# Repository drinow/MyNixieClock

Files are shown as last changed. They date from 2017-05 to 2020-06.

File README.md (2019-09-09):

# 辉光钟--By drinow
## 条目解释
- MyNixie/Version2.0为工程文件，其余为一些资料或者测试数据

## 实物图
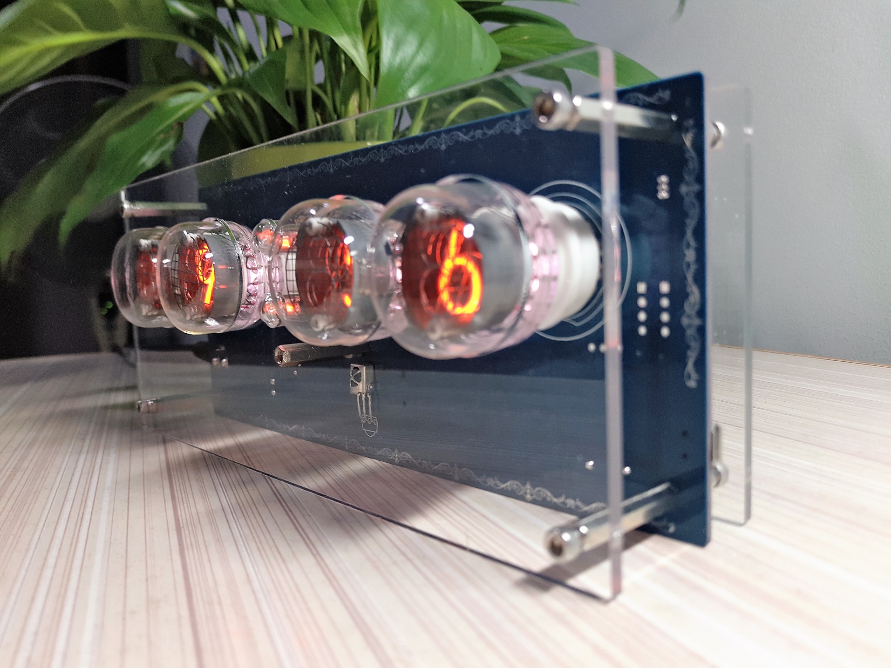
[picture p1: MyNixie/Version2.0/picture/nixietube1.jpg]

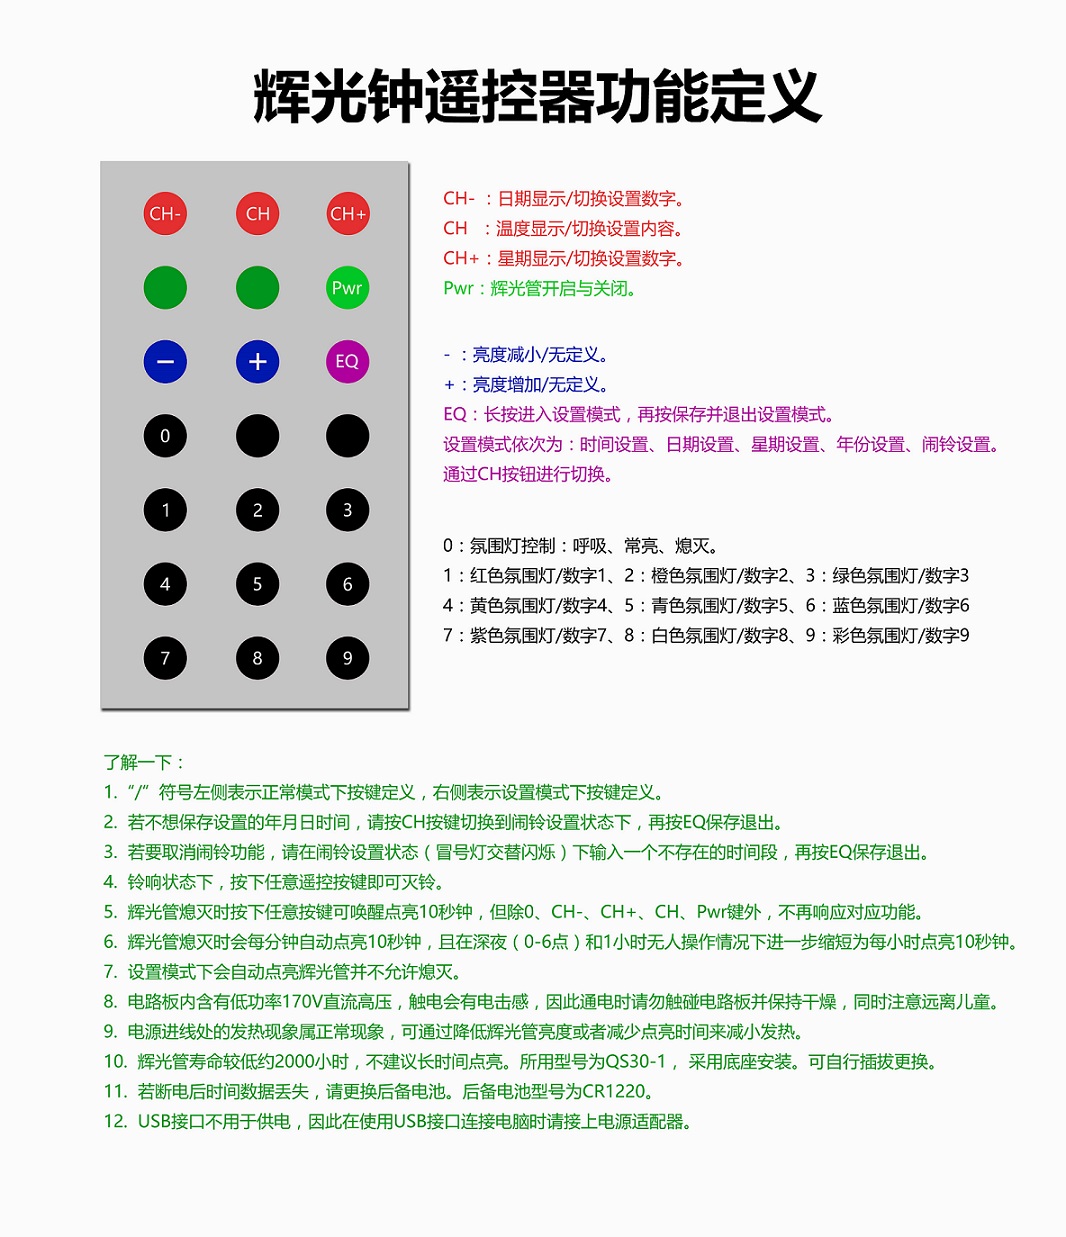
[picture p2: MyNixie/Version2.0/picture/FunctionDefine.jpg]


## 硬件错误
- IRF740的封装画的有些小了，有点难焊，其余没有问题；
- CH340串口电路封装错误导致无法使用DTR、RTS，但可正常通信；
- 上面两个错误已经尝试修复，直接打开工程就是了，未修复的原文件在制板文件夹里

## 重要变化
- 已支持湿度检测功能(传感器SHT20),但需要改装硬件（拆下R3、C3。SHT20传感器占用了[KEY GND 3V3 LAMP]排针孔）,同时
未添加湿度传感器自检代码因此对于未改装的电路烧录此程序会运行异常。
- 你可以通过全局搜索来屏蔽/删除相关变量：SHT20.TEMP_POLL, SHT20.HUMI_POLL，以使得无SHT20的钟正常运行。

## 支持的功能
	1.时分显示
	2.日期显示
	3.温湿度显示
	4.8种单色灯+1种彩色灯+1种彩虹灯
	5.氛围灯呼吸、常亮、关闭功能
	6.防阴极中毒
	7.一组闹铃
	8.遥控器控制
	9.整点报时
	10.自动夜间免打扰

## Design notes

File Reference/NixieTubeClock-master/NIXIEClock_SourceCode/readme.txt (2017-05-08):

基于stm32单片机制作
开发环境为KEIL4

已完成时钟显示功能
时钟日期显示切换与关闭辉光管显示未完成

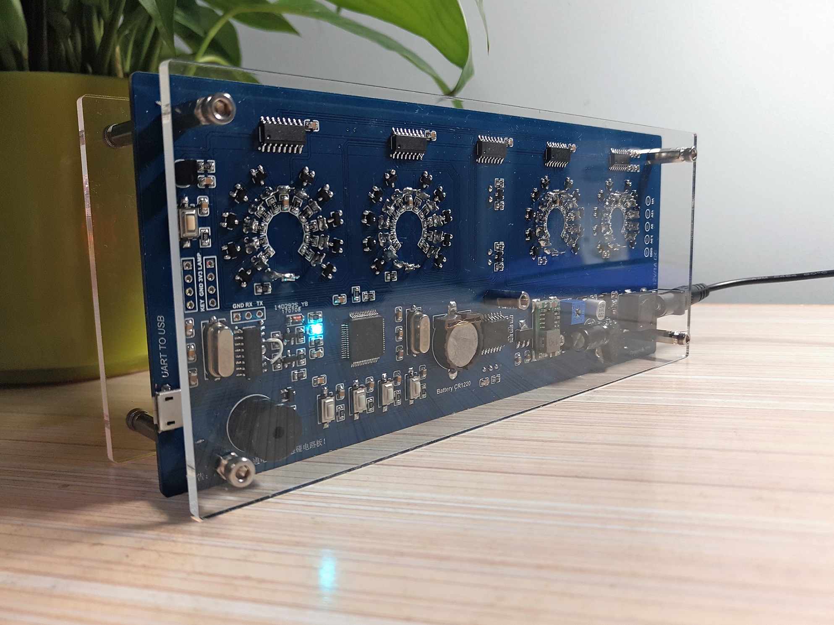
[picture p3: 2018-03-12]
MyNixie/Version2.0/picture/nixietube2.jpg

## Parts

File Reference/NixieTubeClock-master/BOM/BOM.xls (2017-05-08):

商品明细列表
序号 | 商品编号 | 厂家型号/封装 | 商品名称 | 订购数量 | 单价(在线支付) | 金额(在线支付)
1 | C26545 | 暖白3528LED灯珠/3528 | 暖白 3528 LED灯珠 编带 环保 | 50个 | ￥0.0436/个 | ￥2.18
2 | C55509 | L78M05CDT-TR/DPAK | L78M05CDT-TR 编带 环保 | 1片 | ￥1.00/片 | ￥1.00
3 | C41846 | XL-2838L/直插 | 接收头（塑封鼻梁状接收距离远） 袋装 环保 | 1只 | ￥1.00/只 | ￥1.00
4 | C9866 | DS3231SN/SOIC16_75MM | DS3231SN 编带 环保 | 1片 | ￥13.27/片 | ￥13.27
5 | C59928 | HV221M016E077R/6.3*7.7 | 220uF 16V 编带 环保 | 10只 | ￥0.326/只 | ￥3.26
6 | C34268 | RS1G/SMA | RS1G 编带 环保 | 50个 | ￥0.054/个 | ￥2.70
7 | C8515 | MMBTA42 1D/SOT-23-3 | MMBTA42 编带 环保 | 20个 | ￥0.1175/个 | ￥2.35
8 | C53425 | DC50插座 温度范围-30~70℃ 耐压AC50/9x11x14.2 | DC50 φ5.5插座 温度范围-30~70℃ 耐压AC50 袋装 环保 | 5个 | ￥0.596/个 | ￥2.98
9 | C10152 | SMDRI127-331MT/127 | 330uH ±20% 编带 | 2只 | ￥1.00/只 | ￥2.00
10 | C9836 | CR1220-2/贴片 | CR1220-2 电池卧式底坐 盒装 环保 | 1个 | ￥1.00/个 | ￥1.00
11 | C32078 | MC34063ADR2G/SOIC8_39MM | MC34063ADR2G 编带 环保 | 1个 | ￥1.14/个 | ￥1.14
12 | C59368 | KM100M250F115A/8*11.5 | 10uF 250V 袋装 环保 | 10只 | ￥0.292/只 | ￥2.92
13 | C36578 | 1N4007W A7/SOD-123FL | 1N4007W A7 编带 环保 | 50个 | ￥0.0476/个 | ￥2.38
14 | C5408 | 纽扣电池/CR1220/ | 电池/ CR1220 盒装 环保 | 1个 | ￥1.00/个 | ￥1.00
15 | C20818 | SMD2018P100TF/SMD-2018 | 1.00A 自恢复型 | 5片 | ￥0.476/片 | ￥2.38
16 | C5446 | XC6206P332MR/SOT-23-3 | XC6206P332MR 编带 环保 | 1个 | ￥1.00/个 | ￥1.00
17 | C8735 | STM32F103RBT6/LQFP64_10X10X05P | STM32F103RBT6 托盘 环保 | 2个 | ￥13.66/个 | ￥27.32
18 | C2646 | IRF840STRPBF/TO-263-2(DDPAK) | IRF840STRPBF 编带 环保 | 1片 | ￥5.97/片 | ￥5.97
19 | C8077 | ZMM75/LL-34 | ZMM75 编带 环保 | 10片 | ￥0.169/片 | ￥1.69
20 | C18560 | 8MHz ±20PPm 20pF/5032_2P | 8MHz ±20ppm 20pF 编带 环保 | 2个 | ￥1.40/个 | ￥2.80
21 | C37634 | S9013W/SOT-323 | S9013W J3 编带 环保 | 10个 | ￥0.13/个 | ￥1.30

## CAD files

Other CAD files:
MyNixie/Version2.0/Hardware/外壳/亚克力外壳.dwg

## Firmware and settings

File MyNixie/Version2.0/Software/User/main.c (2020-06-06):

/**
  ******************************************************************************
  * @file    main.c
  * @author  fire
  * @version V1.0
  * @date    2013-xx-xx
  * @brief   systick系统定时器
  ******************************************************************************
  * @attention
  *
  * 实验平台:野火 ISO-MINI STM32 开发板
  * 论坛    :http://www.chuxue123.com
  * 淘宝    :http://firestm32.taobao.com
  *
  ******************************************************************************
  */

#include "include.h"

/**
  * @brief  主函数
  * @param  无
  * @retval 无
  */
void SettingFunc(void);
void CheckAlarm(void);
void OnTimeLightCheck(void);
void DealRemoteSignal(void);
void OnTimeAlarm(void);
void Recovery(void);
void EE_ReadConfig(void);
void Breathing(void);
void JumpToISP(void);
void NVIC_Config(void);

extern u32 __IO tick;
extern u8 SecAlarm;
extern u8 __IO Breath_Frq;
extern u8 __IO Period_1S;
extern u8 __IO Pulse;
extern float LightCoe;
extern float Ruse,Guse,Buse;
extern u8 BeepDelayTime100ms;

__IO u8 RemoteKey=DEFAULT;
u8 ShowState=DEFAULT;
__IO u32 LightOnSecCnt=0;
__IO u32 RuntimeSecCnt=0;
u16 LightTime1H=0;
u16 RunTime1H=0;
__IO u16 LightLevel=180;
u8 Setting=0;
u8 SetChannel=0;//设置模式下的通道选择
u8 SetType=0;//设置类型选择
u8 NewNum=0xff;//期望被设置的数
u8 FirstRunFlag=0;
u16 EE_tmp=0;
__IO u8 AlarmState=0;//又是闹铃启动标志位又是闹铃计时变量，单位为秒
__IO u8 AlarmSwitch=0;//闹铃开关
__IO u8 ForceLightOn=0;
int main(void)
{
    LED_GPIO_Config();
    USART1_Config();
    SysTick_Init();
    NVIC_Config();
    FLASH_Unlock();
    EE_Init();

    KEY_GPIO_Config();
    hc595_init();
    DS18B20_Init();
    DS3231_Config();
    SHT2x_Init();
    BeepInit();
    WS2812_Init();
    Remote_Init();
    HC595_PWM_Init();

    EE_ReadConfig();

    Nixie_Test();

//    SetTime.year =0x17;
//    SetTime.month =0x07;
//    SetTime.date =0x28;
//    SetTime.hour =0x16;
//    SetTime.min =0x51;
//    SetTime.sec =0x0;
//    SetTime.week =0x05;
//    DS3231_WriteTime(&SetTime);
//    DS3231_WriteTime(&SetTime);
//  while(1)
//    {
//        u32 i=0,j=0;
//        for(;j<3;j++)
//            for(;i<0xffff;i++);
//        printf("temp:%.2f ",SHT2x_GetTempPoll());//不能读太快。
//        printf("humi:%.2f\r\n",SHT2x_GetHumiPoll());
//    }
//    RunTime1H = 25046;
//    LightTime1H = 16211;
//    EE_SaveConfig();
    
    Nixie_Light_Ctl(LightLevel);
    ForceLightOn=1;
    for(;;)
    {
        Beep_Alarm();//蜂鸣器控制
        SettingFunc();//设置功能
        Nixie_DealRemote(&ShowState);//遥控信号解析
        if(SecAlarm)
        {
            SecAlarm=0;
            RuntimeSecCnt++;
            if(LightLevel!=0||TIM2->CCR4!=0)LightOnSecCnt++;//点亮的时间记录
            if(RuntimeSecCnt>=3600){RuntimeSecCnt=0;RunTime1H++; EE_SaveConfig();}//运行时长记录
            if(LightOnSecCnt>=3600){LightOnSecCnt=0;LightTime1H++;}
            if(GetTime.sec==0) Nixie_Cathode_Prevention();//阴极保护
            SHT20.HUMI_POLL    =SHT2x_GetHumiPoll();//未添加温湿度传感器则一定要屏蔽
            SHT20.TEMP_POLL    =SHT2x_GetTempPoll();//未添加温湿度传感器则一定要屏蔽
            DS18B20_Temp=DS18B20_Get_Temp();//温度传感器
            Nixie_Show(&ShowState);//显示函数
            OnTimeLightCheck();//遥控唤醒或强制点亮10秒
            OnTimeAlarm();//整点报时
            CheckAlarm();//闹钟检查
            LED1_TOGGLE;//运行状态指示
            //DEBUG
            printf("D:%02x-%02x T:%02x:%02x:%02x Wk:%x ",GetTime.month,GetTime.date,GetTime.hour ,GetTime.min ,GetTime.sec,GetTime.week );
            printf("Tmp:%3.1f℃ Humi:%3.1f%% | ",(DS18B20_Temp+SHT20.TEMP_POLL)/2 ,SHT20.HUMI_POLL);
            printf("LLvl:%d ",LightLevel);
            printf("FosLt:%d ",ForceLightOn);
            printf("Alm:%d ",AlarmState);
            printf("RmRdy:%d ",Remote_Rdy);
            printf("Rmkey:%d ",RemoteKey);
            printf("RmCnt:%d ",Remote_Cnt);
            printf("RGBste:%d | ",RGB_Msg.state);
            printf("LT:%dD-%02d:%02d:%02d ",(LightTime1H*60+LightOnSecCnt/60)/60/24,(LightTime1H*60+LightOnSecCnt/60)/60%24,(LightTime1H*60+LightOnSecCnt/60)%60,LightOnSecCnt%60);
            printf("RT:%dD-%02d:%02d:%02d ",(RunTime1H*60+RuntimeSecCnt/60)/60/24,(RunTime1H*60+RuntimeSecCnt/60)/60%24,(RunTime1H*60+RuntimeSecCnt/60)%60,RuntimeSecCnt%60);
                        printf("\r\n");
        }
        Breathing();//呼吸灯
        DealRemoteSignal();//处理遥控信号
        if((Read_Key(KEY1)==0) && (Read_Key(KEY2)==0))//进入ISP
        {
            Nixie_Test();
            Beep_State(800000);
            JumpToISP();
        }
    }
}

void Breathing(void)
{
    //呼吸灯效果
    if(Breath_Frq)
    {
//      SysTick->CTRL &= ~ SysTick_CTRL_ENABLE_Msk;
//            __disable_irq();
      WS2812_Breath();
      Breath_Frq=0;
//            __enable_irq();
//      SysTick->CTRL |=  SysTick_CTRL_ENABLE_Msk;
    }
}


void EE_ReadConfig(void)
{
  //读取设置值
    EE_ReadVariable(VirtAddVarTab[FirstRunFlagAddr],&EE_tmp);FirstRunFlag=EE_tmp;
    if(FirstRunFlag!=0xAA)
    {
        FirstRunFlag=0xAA;
        Recovery();
    }

    EE_ReadVariable(VirtAddVarTab[RunTimeAddr],&EE_tmp);RunTime1H=EE_tmp;
    EE_ReadVariable(VirtAddVarTab[LightTimeAddr],&EE_tmp);LightTime1H=EE_tmp;
    EE_ReadVariable(VirtAddVarTab[LightLevelAddr],&EE_tmp);LightLevel=EE_tmp;
    EE_ReadVariable(VirtAddVarTab[RGBStateAddr],&EE_tmp);RGB_Msg.state=(EffectState_e)EE_tmp;
    EE_ReadVariable(VirtAddVarTab[AlarmAddr],&EE_tmp);Alarm.hour =(EE_tmp&0xff00)>>8;Alarm.min =EE_tmp&0x00ff;
    EE_ReadVariable(VirtAddVarTab[RGBStateAddr],&EE_tmp);RGB_Msg.state=(EffectState_e)EE_tmp;
    EE_ReadVariable(VirtAddVarTab[RMsgAddr],&EE_tmp); RGB_Msg.R=EE_tmp;
    EE_ReadVariable(VirtAddVarTab[GMsgAddr],&EE_tmp); RGB_Msg.G=EE_tmp;
    EE_ReadVariable(VirtAddVarTab[BMsgAddr],&EE_tmp); RGB_Msg.B=EE_tmp;
    EE_ReadVariable(VirtAddVarTab[RGBModeAddr],&EE_tmp);RGB_Msg.mode=(ColorMode_e)EE_tmp;
    EE_ReadVariable(VirtAddVarTab[AlarmSwitchAddr],&EE_tmp);AlarmSwitch=EE_tmp;
    EE_ReadVariable(VirtAddVarTab[LightCoeAddr],&EE_tmp);LightCoe=EE_tmp/100.0;

    if(RGB_Msg.mode==SINGLECOLOR)
    {
        RcdMAX_RGB[TUBE0][RED]=RGB_Msg.R;RcdMAX_RGB[TUBE0][GREEN]=RGB_Msg.G;RcdMAX_RGB[TUBE0][BLUE]=RGB_Msg.B;
        RcdMAX_RGB[TUBE1][RED]=RGB_Msg.R;RcdMAX_RGB[TUBE1][GREEN]=RGB_Msg.G;RcdMAX_RGB[TUBE1][BLUE]=RGB_Msg.B;
        RcdMAX_RGB[TUBE2][RED]=RGB_Msg.R;RcdMAX_RGB[TUBE2][GREEN]=RGB_Msg.G;RcdMAX_RGB[TUBE2][BLUE]=RGB_Msg.B;
        RcdMAX_RGB[TUBE3][RED]=RGB_Msg.R;RcdMAX_RGB[TUBE3][GREEN]=RGB_Msg.G;RcdMAX_RGB[TUBE3][BLUE]=RGB_Msg.B;
    }

    printf("RunTime  :%d Hour \r\n",RunTime1H);
    printf("LightTime :%d Hour \r\n",LightTime1H);
    printf("LightLevel:%d \r\n",LightLevel);
    printf("LightCoe  :%.2f \r\n",LightCoe);
    printf("RGB:State-%d Mode-%d\r\n",RGB_Msg.state,RGB_Msg.mode);
    printf("R:%d G:%d B:%d  \r\n",RGB_Msg.R,RGB_Msg.G,RGB_Msg.B);
    printf("Alarm:%x:%x Switch:%d\r\n",Alarm.hour,Alarm.min,AlarmSwitch);
}

//恢复初始化设置
void Recovery(void)
{
    printf("Factory Reseting...\r\n\r\n");
    Alarm.hour=Alarm.min=0x88;
    AlarmSwitch=0;
    RGB_Msg.R=RGB_Msg.G=RGB_Msg.B=255;
    RGB_Msg.mode=RAINBOW;
    RGB_Msg.state=EFFECTS_ON;
//    RunTime1H=LightTime1H=0;
    LightLevel=180;
    LightCoe=0.7;

    EE_WriteVariable(VirtAddVarTab[LightTimeAddr],LightTime1H);
    EE_WriteVariable(VirtAddVarTab[LightLevelAddr],LightLevel);
    EE_WriteVariable(VirtAddVarTab[RGBStateAddr],RGB_Msg.state);
    EE_WriteVariable(VirtAddVarTab[AlarmAddr],((u16)Alarm.hour<<8)|Alarm.min);
    EE_WriteVariable(VirtAddVarTab[RunTimeAddr],RunTime1H);
    EE_WriteVariable(VirtAddVarTab[RMsgAddr],RGB_Msg.R);
    EE_WriteVariable(VirtAddVarTab[GMsgAddr],RGB_Msg.G);
    EE_WriteVariable(VirtAddVarTab[BMsgAddr],RGB_Msg.B);
    EE_WriteVariable(VirtAddVarTab[RGBModeAddr],RGB_Msg.mode);
    EE_WriteVariable(VirtAddVarTab[AlarmSwitchAddr],AlarmSwitch);
    EE_WriteVariable(VirtAddVarTab[FirstRunFlagAddr],FirstRunFlag);
    EE_WriteVariable(VirtAddVarTab[LightCoeAddr],(u16)(LightCoe*100));
    Beep_State(800000*2);

    printf("RunTime:%d Hour \r\n",RunTime1H);
    printf("LightTime:%d Hour \r\n",LightTime1H);
    printf("LightLevel:%d \r\n",LightLevel);
    printf("RGB:State-%d Mode-%d\r\n",RGB_Msg.state,RGB_Msg.mode);
    printf("R:%d G:%d B:%d  \r\n",RGB_Msg.R,RGB_Msg.G,RGB_Msg.B);
    printf("Alarm:%x:%x Switch:%d\r\n\r\n",Alarm.hour,Alarm.min,AlarmSwitch);
    Nixie_Light_Ctl(LightLevel);
}

//遥控按键处理
void DealRemoteSignal(void)
{
    static u8 finish=0;
    if(Remote_Cnt==0)
        finish=0;
    RemoteKey=Remote_Process();
    if(RemoteKey==SHOWTEMP||RemoteKey==SHOWDATE||RemoteKey==SHOWWEEK||RemoteKey==SHOWSWITCH||\
         RemoteKey==SETTING ||RemoteKey==RGBSTATE||RemoteKey==REDCOLOR||RemoteKey==ORGCOLOR||\
         RemoteKey==YELCOLOR||RemoteKey==GRNCOLOR||RemoteKey==CYACOLOR||RemoteKey==BLUCOLOR||\
         RemoteKey==PURCOLOR||RemoteKey==WHTCOLOR||RemoteKey==COLORFUL||RemoteKey==LIGHT_UP||\
         RemoteKey==LIGHT_DN||RemoteKey==PREV    ||RemoteKey==NEXT    ||RemoteKey==P100    ||RemoteKey==P200)//有些宏定义相同数值的不再写上
    {
        if(Remote_Cnt<=5&&finish==0)//短按
        {
            finish=1;
            AlarmState=0xff;
            if(GetTime.hour>=0x06&&GetTime.hour<0x22)
                Beep_State(1);
            if(LightLevel==0)//熄灭状态
            {
                if(RemoteKey==LIGHT_UP||RemoteKey==LIGHT_DN||RemoteKey==SETTING)
                    ShowState=DEFAULT;
                else
                    ShowState=RemoteKey;
                Nixie_Show(&ShowState);
                ForceLightOn=1;Nixie_Light_Ctl(180);
            }
            else //
            {
                if(RemoteKey==SETTING)
                    ShowState=DEFAULT;
                else
                    ShowState=RemoteKey;
                Nixie_Show(&ShowState);
            }

        }
        else if(Remote_Cnt==15)//长按
        {
            if(RemoteKey==SETTING)
            {
                Beep_State(1);
                ShowState=RemoteKey;
            }
            else if(RemoteKey==SHOWSWITCH)
            {
                Recovery();
            }
        }
        else
        {
        }
        printf("RemoteKey:%d ",RemoteKey);//显示键值
        printf("cnt:%d \r\n",Remote_Cnt);//显示按键次数
    }
    else if(RemoteKey!=0)
    {
      printf("UnexpectRemoteKey:%d ",RemoteKey);//显示键值
          printf("UnexpectCnt:%d \r\n",Remote_Cnt);//显示按键次数
    }
}

//检查闹铃，并持续响60秒
//灭铃控制在遥控那里
void CheckAlarm(void)
{
    if(AlarmSwitch)
    {
        //检查闹铃
        if(Alarm.hour==GetTime.hour&&Alarm.min==GetTime.min&&GetTime.sec==0)
            AlarmState=1;
        //闹铃计时
        if(AlarmState>0&&AlarmState<32)
        {
            AlarmState++;if(LightLevel==0)Nixie_Light_Ctl(180);
        }
        if(AlarmState==32)
        {
            AlarmState=0xff;Beep(0);if(LightLevel==0)ForceLightOn=1;
        }
    }
    if(AlarmState==0xff&&Alarm.min!=GetTime.min)AlarmState=0;
}

//灭灯时在整点时强制点亮10秒钟
void OnTimeLightCheck(void)
{
    if(LightLevel==0)
    {
        if(ForceLightOn)
            ForceLightOn++;

        if(GetTime.hour<0x06)//半夜修改为1小时间隔点亮
        {
            if(GetTime.min == 0 && GetTime.sec == 0)
            {
                ForceLightOn++;
            }
        }
        else
        {
            if(GetTime.sec == 0x00||GetTime.sec == 0x10||GetTime.sec == 0x20||
               GetTime.sec == 0x30||GetTime.sec == 0x40||GetTime.sec == 0x50)
            {
                ForceLightOn++;
            }
        }

        if(ForceLightOn>0&&ForceLightOn<6)
            Nixie_Light_Ctl(180);

        if(ForceLightOn>=6&&GetTime.sec>0x10&&GetTime.sec<0x50)
        {
            ForceLightOn=0;
            Nixie_Light_Ctl(0);
        }
    }
    else
    {
        ForceLightOn=0;
    }
}

//9-21点整点报时
void OnTimeAlarm(void)
{
    if(GetTime.sec==0&&GetTime.min==0&&GetTime.hour>0x08&&GetTime.hour<0x22&&AlarmState==0)
    {
        Beep_OnTimeAlarm();
    }
}

void SettingFunc(void)
{
    u8 lightflag=0;
  if(Setting)
  {
    SetTime.year=GetTime.year;
    SetTime.month=GetTime.month;
    SetTime.date=GetTime.date;
    SetTime.hour=GetTime.hour;
    SetTime.min=GetTime.min;
    SetTime.sec=0;
    SetTime.week=GetTime.week;
    SetChannel=0;
        SetType=4;//先进入Alarm设置模式下
        if(LightLevel==0)
        {
            Nixie_Light_Ctl(180);//强制点亮
            lightflag=1;
        }
    while(Setting)//注意进来后因为未松按钮导致又退出去
    {
      Nixie_DealRemote(&ShowState);
      if(SecAlarm)
      {
        SecAlarm=0;
                RuntimeSecCnt++;
        if(LightLevel!=0)LightOnSecCnt++;//运行时间计时
                if(RuntimeSecCnt==3600){RuntimeSecCnt=0;RunTime1H++;}
        if(LightOnSecCnt==3600){LightOnSecCnt=0;LightTime1H++;}
                if(GetTime.sec==0)
                {
                    Nixie_Cathode_Prevention();
                }
                LED1_TOGGLE;
      }
      if(Pulse)
      {
        Nixie_Set_Show();
        Pulse=0;
      }

            RemoteKey=Remote_Process();
            if(RemoteKey!=0&&Remote_Cnt==1)//利用Remote_Cnt不自动清空，防止长按设置后直接跳进来
            {
                Beep_State(5);
                ShowState=RemoteKey;
//                printf("RemoteKey:%d ",RemoteKey);//显示键值
//                printf("cnt:%d \r\n",Remote_Cnt);//显示按键次数
            }
            else ShowState=DEFAULT;

    }
        if(lightflag==1)
            Nixie_Light_Ctl(0);
    //闹钟设置模式下不修改时间
    if(SetType==SETALARM)
    {
      Dot1_ON;Dot2_ON;
            if(Alarm.hour>0x24||Alarm.min>=60)AlarmSwitch=0;else AlarmSwitch=1;
            EE_SaveConfig();
    }
    else
        {
      DS3231_WriteTime(&SetTime);
        }
  }
}

void JumpToISP(void)
{
    //程序跳转不复位外设，建议对一些可能导致问题的外设进行反初始化DeInit，如SysTick。
    //看门狗一旦初始化不能被关闭，因此如果使用了看门狗，则在调用该函数前，必须先复位系统，并在初始化看门狗之前调用该函数。
    #define ISPAddress 0x1FFFF000 
    uint32_t ispJumpAddr;//ISP程序的跳转地址，既程序入口
    uint32_t ispSpValue;//IAP程序的SP初值，即栈指针
    void (*Jump_To_ISP)(void);//定义一个函数指针

    SysTick->CTRL=0x00;       //关闭计数器
    SysTick->VAL =0X00;       //清空计数器	
    //__set_FAULTMASK(1);   //关闭所有中断
    //__set_CONTROL(0);     //将PSP指针切换为MSP指针，适用于APP使用OS情况
    //        NVIC_SystemReset();      //NVIC重置
    if (((*(__IO uint32_t*)ISPAddress) & 0x2FFE0000 ) == 0x20000000)
    { 
        ispSpValue  = *(__IO uint32_t*)ISPAddress;
        ispJumpAddr = *(__IO uint32_t*)(ISPAddress+4);


        /* 初始化 Stack Pointer */
        __set_MSP(ispSpValue);

        /* Jump to isp */
        Jump_To_ISP = (void (*)(void))ispJumpAddr;
        Jump_To_ISP();
    }
}

void NVIC_Config(void)
{
    NVIC_InitTypeDef NVIC_InitStructure;
    NVIC_PriorityGroupConfig(NVIC_PriorityGroup_2);

    /* Enable the USARTy Interrupt */
    NVIC_InitStructure.NVIC_IRQChannel = USART1_IRQn;
    NVIC_InitStructure.NVIC_IRQChannelPreemptionPriority = 0;
    NVIC_InitStructure.NVIC_IRQChannelSubPriority = 2;
    NVIC_InitStructure.NVIC_IRQChannelCmd = ENABLE;
    NVIC_Init(&NVIC_InitStructure);

  //DS3231 INT
  NVIC_InitStructure.NVIC_IRQChannel = EXTI2_IRQn;
    NVIC_InitStructure.NVIC_IRQChannelPreemptionPriority = 0;
    NVIC_InitStructure.NVIC_IRQChannelSubPriority = 1;
    NVIC_InitStructure.NVIC_IRQChannelCmd = ENABLE;
    NVIC_Init(&NVIC_InitStructure);

  //HX1838 INT
  NVIC_InitStructure.NVIC_IRQChannel = EXTI9_5_IRQn;
    NVIC_InitStructure.NVIC_IRQChannelPreemptionPriority = 0;
    NVIC_InitStructure.NVIC_IRQChannelSubPriority = 0;
    NVIC_InitStructure.NVIC_IRQChannelCmd = ENABLE;
    NVIC_Init(&NVIC_InitStructure);
}


/*********************************************END OF FILE**********************/

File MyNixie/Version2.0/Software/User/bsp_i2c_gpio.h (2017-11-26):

#ifndef _BSP_I2C_GPIO_H
#define _BSP_I2C_GPIO_H

#include <inttypes.h>

#define I2C_WR	0		/* 写控制bit */
#define I2C_RD	1		/* 读控制bit */

/* 定义I2C总线连接的GPIO端口, 用户只需要修改下面4行代码即可任意改变SCL和SDA的引脚 */
#define GPIO_PORT_I2C	GPIOB			/* GPIO端口 */
#define RCC_I2C_PORT 	RCC_APB2Periph_GPIOB		/* GPIO端口时钟 */
#define I2C_SCL_PIN		GPIO_Pin_3			/* 连接到SCL时钟线的GPIO */
#define I2C_SDA_PIN		GPIO_Pin_4			/* 连接到SDA数据线的GPIO */

#define I2C_SCL_1()  GPIO_SetBits(GPIO_PORT_I2C, I2C_SCL_PIN)		/* SCL = 1 */
#define I2C_SCL_0()  GPIO_ResetBits(GPIO_PORT_I2C, I2C_SCL_PIN)		/* SCL = 0 */

#define I2C_SDA_1()  GPIO_SetBits(GPIO_PORT_I2C, I2C_SDA_PIN)		/* SDA = 1 */
#define I2C_SDA_0()  GPIO_ResetBits(GPIO_PORT_I2C, I2C_SDA_PIN)		/* SDA = 0 */

#define I2C_SDA_READ()  GPIO_ReadInputDataBit(GPIO_PORT_I2C, I2C_SDA_PIN)	/* 读SDA口线状态 */
#define I2C_SCL_READ()  GPIO_ReadInputDataBit(GPIO_PORT_I2C, I2C_SCL_PIN)	/* 读SDA口线状态 */


void i2c_Start(void);
void i2c_Stop(void);
void i2c_SendByte(uint8_t _ucByte);
uint8_t i2c_ReadByte(void);
uint8_t i2c_WaitAck(void);
void i2c_Ack(void);
void i2c_NAck(void);
uint8_t i2c_CheckDevice(uint8_t _Address);
void i2c_CfgGpio(void);
void i2c_Delay(void);

#endif

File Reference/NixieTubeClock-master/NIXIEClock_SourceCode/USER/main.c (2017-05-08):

// Created By 常曙&沉默的大树
// Last modified date: 2016-01-24
// Location: Chengdu

// TODO: Date/time switch
// TODO: Automatically turn off LED

#include "stm32f10x.h"
#include "HV57708.h"
#include "ds3231.h"
#include <stdbool.h>



u8 dis_data[]={9,3,4,3,3,3};
extern Time_Typedef TimeValue;
extern u8 Display_Time[8];

static bool Neon_status = 0;
static u8 second_previous = 0;

void Neon_Init(void)
{
    Neon_status = 0;
    GPIO_ResetBits(GPIOC, GPIO_Pin_1); // DOT1
    GPIO_ResetBits(GPIOC, GPIO_Pin_0); // DOT2
    GPIO_ResetBits(GPIOC, GPIO_Pin_3); // DOT3
    GPIO_ResetBits(GPIOC, GPIO_Pin_2); // DOT4
}

void Neon_Flip(void) 
{
    Neon_status = !Neon_status;
    if(Neon_status == 1) {
        GPIO_ResetBits(GPIOC, GPIO_Pin_1); // DOT1
        GPIO_ResetBits(GPIOC, GPIO_Pin_0); // DOT2
        GPIO_ResetBits(GPIOC, GPIO_Pin_3); // DOT3
        GPIO_ResetBits(GPIOC, GPIO_Pin_2); // DOT4
    } else {
        GPIO_SetBits(GPIOC, GPIO_Pin_1); // DOT1
        GPIO_SetBits(GPIOC, GPIO_Pin_0); // DOT2
        GPIO_SetBits(GPIOC, GPIO_Pin_3); // DOT3
        GPIO_SetBits(GPIOC, GPIO_Pin_2); // DOT4
    }
}

void LED_Init(void)
{
    GPIO_InitTypeDef	GPIO_InitStructure;
    
    RCC_APB2PeriphClockCmd(RCC_APB2Periph_GPIOC,ENABLE);
	GPIO_InitStructure.GPIO_Pin = GPIO_Pin_3|GPIO_Pin_5|GPIO_Pin_6|GPIO_Pin_7;	
	GPIO_InitStructure.GPIO_Mode = GPIO_Mode_Out_PP;														//推挽输出
	GPIO_InitStructure.GPIO_Speed = GPIO_Speed_50MHz;														//速度50MHZ
	GPIO_Init(GPIOA,&GPIO_InitStructure);
    
    RCC_APB2PeriphClockCmd(RCC_APB2Periph_GPIOC,ENABLE);
	GPIO_InitStructure.GPIO_Pin = GPIO_Pin_4|GPIO_Pin_5;	
	GPIO_InitStructure.GPIO_Mode = GPIO_Mode_Out_PP;														//推挽输出
	GPIO_InitStructure.GPIO_Speed = GPIO_Speed_50MHz;														//速度50MHZ
	GPIO_Init(GPIOC,&GPIO_InitStructure);
}

void LED_ON()
{
    GPIO_ResetBits(GPIOA,GPIO_Pin_3|GPIO_Pin_5|GPIO_Pin_6|GPIO_Pin_7);
    GPIO_ResetBits(GPIOC,GPIO_Pin_4|GPIO_Pin_5);
}

void LED_OFF()
{
    GPIO_SetBits(GPIOA,GPIO_Pin_3|GPIO_Pin_5|GPIO_Pin_6|GPIO_Pin_7);
    GPIO_SetBits(GPIOC,GPIO_Pin_4|GPIO_Pin_5);
}

int main(void)
{	
	//u32 i,j;
	//u8 x=0;
	
	HV57708_Init(HV57708_MODE_NORMAL);
	IIC_GPIO_Config(); 
    Neon_Init();
    LED_Init();
    //LED_ON();
    //Neon_Flip();
    
	//GPIO_SetBits(GPIOA,GPIO_Pin_3|GPIO_Pin_5|GPIO_Pin_6|GPIO_Pin_7);
 	//GPIO_SetBits(GPIOC,GPIO_Pin_4|GPIO_Pin_5);
	//GPIO_SetBits(GPIOC,GPIO_Pin_14|GPIO_Pin_15);
    
    //while(1) {
    //    Neon_Flip();
    //    Delay(5000);
    //}
    
    //HV57708_SendData(0, 0);
    //HV57708_OutputData();
    //Neon_Flip();
    //while(1);
    
   //SetDisplay(dis_data);
   //while(1);
   
//Relay
	//GPIO_ResetBits(GPIOB,GPIO_Pin_9);
	//GPIO_SetBits(GPIOB,GPIO_Pin_9);
	
	//GPIO_SetBits(GPIOC,GPIO_Pin_0|GPIO_Pin_1|GPIO_Pin_2|GPIO_Pin_3);
	
	TimeValue.year=DS3231_YEARDATA;
	TimeValue.month=0x01;
	TimeValue.week=0x07;
	TimeValue.date=0x24;
	TimeValue.hour=0x02;
	TimeValue.minute=0x49;
	TimeValue.second=0x00;

    Time_Handle();
    second_previous = Display_Time[7] - 0x30;
	//DS3231_Time_Init(&TimeValue);
    //Time_Handle();
    //while(1);
	while(1) {
        Time_Handle();
        dis_data[0] = Display_Time[0] - 0x30;
        dis_data[1] = Display_Time[1] - 0x30;
        dis_data[2] = Display_Time[3] - 0x30;
        dis_data[3] = Display_Time[4] - 0x30;
        dis_data[4] = Display_Time[6] - 0x30;
        dis_data[5] = Display_Time[7] - 0x30;
        if(dis_data[5] != second_previous) {
            second_previous = dis_data[5];
            Neon_Flip();
        }
        SetDisplay(dis_data);
        Delay(500);
    }
}

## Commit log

2017-11-26 add pwm light tube
    [MyNixie - HC595.SchDoc, MyNixie - HV57708.SchDoc, MyNixie.PcbDoc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]
2017-12-02 修改了15min计时数据类型
2017-12-03 修正了偶尔自动清除设置的bug
2017-12-05 调整一下结构，更改systick时基，遥控数据判断逻辑
2017-12-24 结构修改 RGB逻辑优化 取消了1小时后进入休眠状态 其他代码优化
2017-12-24 RGB渐变从正弦曲线改为S型曲线
2017-12-27 RGB单色渐变按周期S型曲线规律控制
2018-02-10 RGB单色渐变规律按S型曲线规律控制
2018-02-10 增加README解释
2018-03-12 整理了文件结构目录
    [BOM.xls, MC34063.PrjPCB, MC34063.xlsx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]
2018-03-12 调整文件结构目录
2019-09-09 扩大显示范围u8-u16
2019-09-09 更改为1hour存储一次
2020-06-06 增加进入ISP代码，应该修复了Flash丢失数据的bug
